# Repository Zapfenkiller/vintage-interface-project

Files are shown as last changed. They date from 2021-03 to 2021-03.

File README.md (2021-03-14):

## V. I. P. = **V**intage **I**nterface **P**roject

Ein altehrwürdiges fischertechnik Computing-Interface erhält Anschluss an den
I²C-Bus.

Die Eckdaten:

* I²C-Bus bis 400 kHz maximal
* I²C-Bus bis 100 kHz *ohne* Clock-Stretching
* Level-Shifter für den I²C-Bus eingebaut, Vcc = 1,8 V bis 5,0 V
* Bis zu 4 verschiedene V. I. P. im gleichen Bussegment adressierbar.
* Theoretisch beliebig viele Interfaces kaskadierbar
* I²C-Stecker entspricht 1:1 der I²C-Belegung des fischertechnik
[TX-Controllers 500995](https://ft-datenbank.de/details.php?ArticleVariantId=2f4d3bd4-b293-4f10-9b9d-c2faa8632409)

Was es über die alten Interfaces und den Adapter zu wissen gibt, ist bereits
als Mehrteiler in der ft:pedia veröffentlicht:

* Einführung und jede Menge Steckerbelegungen: [ft:pedia 2/2017, S. 63, V. I. P. - Teil 1](https://www.ftcommunity.de/ftpedia_ausgaben/ftpedia-2017-2.pdf)
* Stromversorgung und Motortreiber: [ft:pedia 3/2017, S. 57, V. I. P. - Teil 2](https://www.ftcommunity.de/ftpedia_ausgaben/ftpedia-2017-3.pdf)
* Eingänge und Watchdog: [ft:pedia 4/2017, S. 36, V. I. P. - Teil 3](https://www.ftcommunity.de/ftpedia_ausgaben/ftpedia-2017-4.pdf)

Hier im Repository sind alle Dokumente über die Hardware (Schaltplan und
Layout) und die Software (C-Sourcecode, Makefile, Hex-File und ein paar Files
für das AVR-Studio) zu finden.

Die Platine für den Adapter muss man sich selbst anfertigen.
Das Layout ist doppelseitig ausgeführt.
Eine Durchkontaktierung wird empfohlen.

Das Hex-File wird via AVR-Studio und STK500 in den angeschlossenen µC
programmiert.
Alternative Möglichkeiten sind natürlich ebenso verwendbar.
Dank des ISP-Steckers auf der Platine kann der µC direkt im Fertiggerät
geflasht werden.
Dieser ISP-Stecker ist 1:1 wie der 6-polige ISP-Stecker vom STK500 belegt.

An sich ist das Projekt abgeschlossen, evaluiert und die Software passt genau
zur Hardware.
Wer trotzdem selbst Hand anlegen möchte, kann dies gerne tun.
Die verwendete Toolchain (ist heutzutage auch alt, aber damit ist das Projekt
nun einmal entwickelt worden):

* µC-Referenz:   ATtiny2313 datasheet Rev. 2543I–AVR–04/06 (www.atmel.com)
* Compiler:      WinAVR-20100110 (http://www.sourceforge.net)
* Debugger:      AVR-Studio 4.18 (www.atmel.com)
* ISP:           Atmel STK500 (z. B. https://www.reichelt.de/Programmer-Entwicklungstools/AVR-STK-500/3/index.html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)
* PCB-CAD:       EAGLE 4.15 (http://www.cadsoft.de)

Gerade im ISP Bereich der Programmer gibt es erheblich günstigere Produkte
als das angegebene STK500.
Bitte im Bedarfsfall mal selbst beim Lieblingsbauteileshop mit dem Suchbegriff
"AVR programmer" stöbern.

Beim EAGLE kann möglicherweise auch eine modernere Version verwendet werden.
Ich habe das *nicht* ausprobiert.

Beim Compiler ändern sich von Version zu Version gerne mal die Definitionen
der Interruptbehandlung. 
Mit der angegebenen Version - und dem hiesigen makefile - klappt das auf
Anhieb.
Für andere Versionen ist möglicherweise massive Nacharbeit im C-Code zu
leisten.
Das Hex-File entspricht dem vorgestellten Sourcecode und kann sofort verwendet
werden.

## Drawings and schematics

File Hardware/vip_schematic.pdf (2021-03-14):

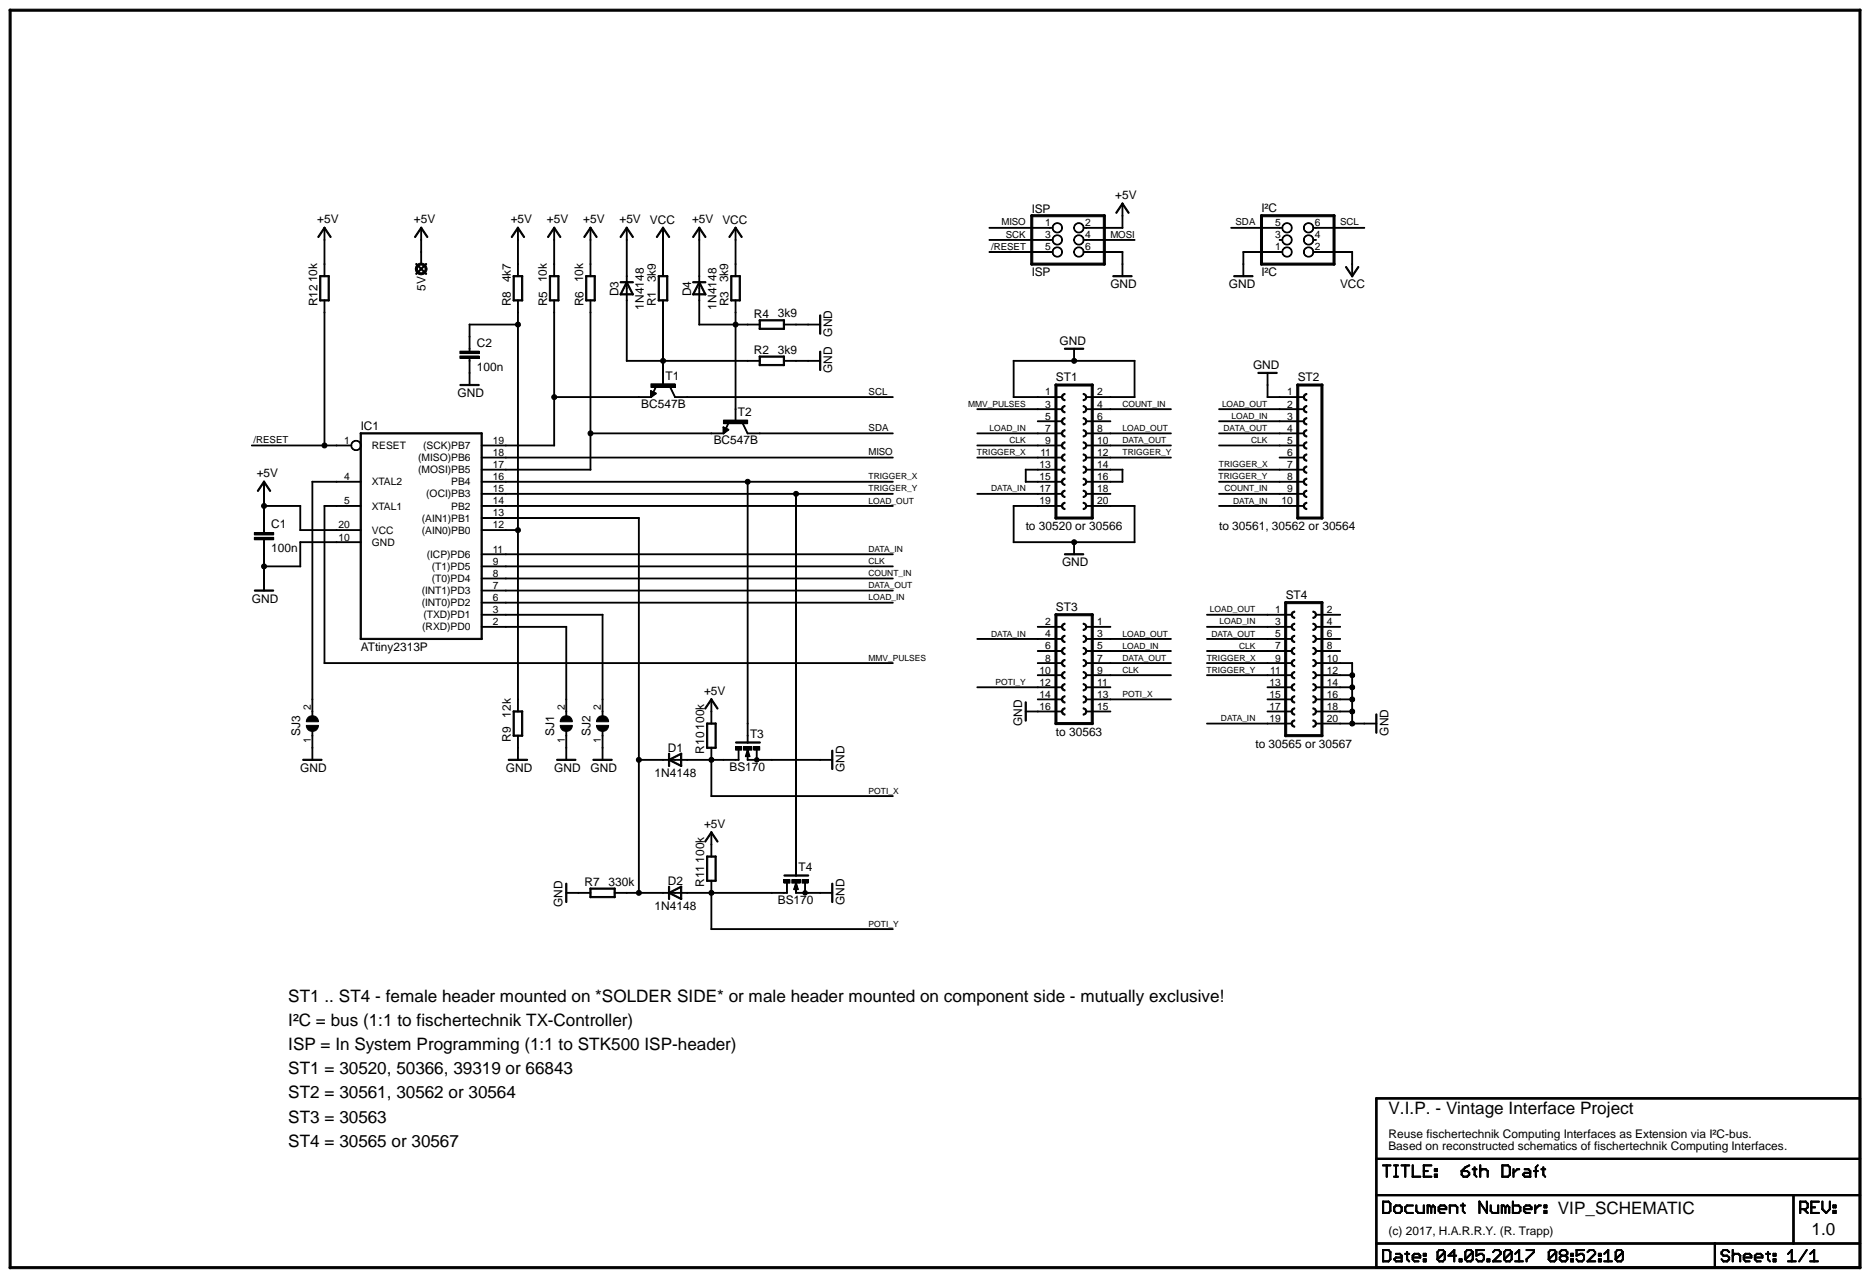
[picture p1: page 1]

ST1 .. ST4 - female header mounted on *SOLDER SIDE* or male header mounted on component side - mutually exclusive!
I²C = bus (1:1 to fischertechnik TX-Controller)
ISP = In System Programming (1:1 to STK500 ISP-header)

Reuse fischertechnik Computing Interfaces as Extension via I²C-bus.
Based on reconstructed schematics of fischertechnik Computing Interfaces.

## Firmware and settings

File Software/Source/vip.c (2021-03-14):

/*****************************************************************************\
 * File:         vip.c
 * Project:      Vintage Interface Project - V.I.P.
 * Initial date: May / 7 / 2017
 * Release rev.: 2017jun28
 * Copyright:    (c) 2017 R. Trapp / H.A.R.R.Y.
 *               All rights reserved.
 * Contact:      h_a_r_r_y_@users.sourceforge.net
 *               <https://forum.ftcommunity.de> => send PN to H.A.R.R.Y.
 * Description:  Adapt vintage fischertechnik Computing Interfaces to I²C-bus.
 *               The Interface thus can be addressed and operated as a slave.
 *               See documentation in archive or ft:pedia 2/2017 ff.
 *               Adjusts automatically to all known interface types:
 *               30520, 30561, 30562, 30563, 30564, 30565, 30566, 30567, 39319,
 *               66843
 *               ATtiny2313 runs off 8MHz, bus speed maximum 100kHz w/o clock-
 *               stretching. 400kHz relies on clock-stretching to slow down the
 *               bus-master!
 * Toolchain:    WinAVR-20100110 (http://www.sourceforge.net)
 *               ATtiny2313 datasheet revision = Rev. 2543I–AVR–04/06
 * WARNING:      This code contains inline assembly and plays lots of other
 *               tricks to optimize for topmost speed where necessary. Due to
 *               this everything must be done here in *one* file. If you dislike
 *               such a coding style you better stay away and stop reading now.
 *               There is the pure 'teaching book' "how-things-work" C-code in
 *               the neighbourhood. Read this equivalent to get an idea of the
 *               functionality. That code also compiles, links and works but if
 *               you compile and use that code, you will get a penalty of
 *               increased execution time - leading also to clock-stretching at
 *               100kHz bus.
 * License:      Redistribution and use in source and binary forms, with or
 *               without modification, are permitted provided that the following
 *               conditions are met:
 *               * Redistributions of source code must retain the above
 *                 copyright notice, this list of conditions and the following
 *                 disclaimer.
 *               * Redistributions in binary form must reproduce the above
 *                 copyright notice, this list of conditions and the following
 *                 disclaimer in the documentation and/or other materials
 *                 provided with the distribution.
 *               * Neither the name of the copyright holders nor the names of
 *                 contributors may be used to endorse or promote products
 *                 derived from this software without specific prior written
 *                 permission.
 * Disclaimer:   THIS SOFTWARE IS PROVIDED BY THE COPYRIGHT HOLDERS AND
 *               CONTRIBUTORS "AS IS" AND ANY EXPRESS OR IMPLIED WARRANTIES,
 *               INCLUDING, BUT NOT LIMITED TO, THE IMPLIED WARRANTIES OF
 *               MERCHANTABILITY AND FITNESS FOR A PARTICULAR PURPOSE ARE
 *               DISCLAIMED. IN NO EVENT SHALL THE COPYRIGHT OWNER OR
 *               CONTRIBUTORS BE LIABLE FOR ANY DIRECT, INDIRECT, INCIDENTAL,
 *               SPECIAL, EXEMPLARY, OR CONSEQUENTIAL DAMAGES (INCLUDING, BUT
 *               NOT LIMITED TO, PROCUREMENT OF SUBSTITUTE GOODS OR SERVICES;
 *               LOSS OF USE, DATA, OR PROFITS; OR BUSINESS INTERRUPTION)
 *               HOWEVER CAUSED AND ON ANY THEORY OF LIABILITY, WHETHER IN
 *               CONTRACT, STRICT LIABILITY, OR TORT (INCLUDING NEGLIGENCE OR
 *               OTHERWISE) ARISING IN ANY WAY OUT OF THE USE OF THIS SOFTWARE,
 *               EVEN IF ADVISED OF THE POSSIBILITY OF SUCH DAMAGE.
\*****************************************************************************/


// ============================================================================
//                         Set MCU clock to 8MHz!
//                      Everything here relies on it!
// ============================================================================

#ifndef F_CPU
#define F_CPU                 8000000UL
#else
#if (F_CPU!=8000000)
#error: F_CPU not set to 8MHz! Readjust project properties!
#endif
#endif


// ============================================================================
//                   Check for ATtiny2313 to be selected
// ============================================================================

#ifndef __AVR_ATtiny2313__
#error: This code is exclusively dedicated to ATtiny2313!
#endif
// Very close relatives could eventually also be used without changes.


/******************************************************************************\
 ******************************************************************************
 *
 *                                Prologue
 *
 ******************************************************************************
\******************************************************************************/


// ============================================================================
// Necessary includes
// ============================================================================

#include <avr/io.h>
#include <avr/interrupt.h>
#include <util/delay.h>


// ============================================================================
//                      Highly Recommended settings
// ============================================================================

// CKSEL3..0      = 0100   = internal 8MHz
// CKDIV          = 1      = no prescaling
// SUT1..0        = 10     = 65ms (slow rising power)
// BODLEVEL2..0   = 101    = 2.7V
// According to documentation just list here those fuse bits which need to get
// programmed ('0'). Unprogrammed ('1') fuses shall not be listed.
   FUSES = 
   {
      .low = (FUSE_SUT0 & FUSE_CKSEL3 & FUSE_CKSEL1 & FUSE_CKSEL0),
      .high = (FUSE_SPIEN & FUSE_BODLEVEL1),
      .extended = (FUSE_SELFPRGEN),
   };


// 'Security'     = Leave open since this code is released to the public.
   LOCKBITS = (LB_MODE_1);


// ============================================================================
// Assign signal names to ports
// ============================================================================

// ft Computing Interface:
// -----------------------
#define CLK                   PD5
#define COUNT_IN              PD4
#define DATA_IN               PD6
#define DATA_OUT              PD3
#define LOAD_IN               PD2
#define LOAD_OUT              PB2
#define MMV_PULSES            PA0
#define TRIGGER_X             PB4
#define TRIGGER_Y             PB3

// I²C bus:
// --------
#define TWIport               PORTB
#define TWIread               PINB
#define TWIddr                DDRB
#define TWIsclBit             PB7
#define TWIsdaBit             PB5

// Miscellaneous:
// --------------
#define MISO_ISP              PB6
#define SJ3                   PA1
#define SJ2                   PD1
#define SJ1                   PD0


// ============================================================================
// Reserve a few(!) registers - to speed up interrupt handling!
// ============================================================================
// Note: Need to do it here so that *everything* is aware of this reservation
//       at compile time!

/// \brief
/// Private storage register for the actual bus state.
// Use of r16 to r31 is mandatory due to CPI instructions
volatile register uint8_t  I2C_private_state asm ("r16");


/// \brief
/// Private storage register for the last received address+R/W field.
volatile register uint8_t  I2C_address_received asm ("r17");


// ============================================================================
// Unexpected Interrupts
// ============================================================================


/// \brief
/// Catches all unexpected interrupts.
/// \detail
/// What to do if any unexpected interrupt occurs? One could reset the appli-
/// cation immediately. And then? Unreliable functionality and really hard to
/// find root cause(s). Whom to report about the fault? No debug interface, no
/// user interface, ... so just ignore this unexpected interrupt. The ones we
/// are interested in are already handled.
EMPTY_INTERRUPT (BADISR_vect);
//  Up to here we assume 10 clocks (7 according to datasheet plus uncertainty)
//  So when RETI has passed we lost roughly 14 clocks @ 8MHz = 1750ns


/******************************************************************************\
 ******************************************************************************
 *
 *                       ft Computing Interface handling
 *                       ===============================
 *
 ******************************************************************************
\******************************************************************************/


// ============================================================================
// Some macros for easier coding
// ============================================================================
// Note: Do not rely on the compiler - force optimum code where necessary!

#define FT_IF_DEFAULT_DDRA    (0<<MMV_PULSES)
#define FT_IF_DEFAULT_PORTA   (1<<MMV_PULSES)
#define FT_IF_DEFAULT_DDRB    ((1<<TRIGGER_X) | (1<<TRIGGER_Y) | (1<<LOAD_OUT))
#define FT_IF_DEFAULT_PORTB   ((1<<TRIGGER_X) | (1<<TRIGGER_Y) | (0<<LOAD_OUT))
#define FT_IF_DEFAULT_DDRD    ((0<<DATA_IN) | (1<<CLK) | (0<<COUNT_IN) | (1<<DATA_OUT) | (1<<LOAD_IN))
#define FT_IF_DEFAULT_PORTD   ((1<<DATA_IN) | (1<<CLK) | (1<<COUNT_IN) | (0<<DATA_OUT) | (0<<LOAD_IN))

#define CLK_rise              asm volatile ("SBI %[port], %[bit]"::[port] "I" (_SFR_IO_ADDR(PORTD)), [bit] "I" (CLK))
#define CLK_fall              asm volatile ("CBI %[port], %[bit]"::[port] "I" (_SFR_IO_ADDR(PORTD)), [bit] "I" (CLK))
#define COMPARATOR_state      ACSR & (1<<ACO)
#define COUNT_IN_state        PIND & (1 << COUNT_IN)
#define COUNT_IN_count        TCNT0
#define DATA_IN_state         PIND & (1 << DATA_IN)
#define DATA_OUT_hi           asm volatile ("SBI %[port], %[bit]"::[port] "I" (_SFR_IO_ADDR(PORTD)), [bit] "I" (DATA_OUT))
#define DATA_OUT_lo           asm volatile ("CBI %[port], %[bit]"::[port] "I" (_SFR_IO_ADDR(PORTD)), [bit] "I" (DATA_OUT))
#define LOAD_IN_rise          asm volatile ("SBI %[port], %[bit]"::[port] "I" (_SFR_IO_ADDR(PORTD)), [bit] "I" (LOAD_IN))
#define LOAD_IN_fall          asm volatile ("CBI %[port], %[bit]"::[port] "I" (_SFR_IO_ADDR(PORTD)), [bit] "I" (LOAD_IN))
#define LOAD_OUT_rise         asm volatile ("SBI %[port], %[bit]"::[port] "I" (_SFR_IO_ADDR(PORTB)), [bit] "I" (LOAD_OUT))
#define LOAD_OUT_fall         asm volatile ("CBI %[port], %[bit]"::[port] "I" (_SFR_IO_ADDR(PORTB)), [bit] "I" (LOAD_OUT))
#define MMV_PULSES_state      PINA & (1 << MMV_PULSES)
#define TRIGGER_MMV(mmv)      PORTB &= (mmv); /*trigger_select;*/
#define TRIGGERs_release      PORTB |= ((1 << TRIGGER_X) | (1 << TRIGGER_Y))

#define DATA_IN_native        0b00000000
#define DATA_IN_inverted      0b11111111
#define no_motor_protection   0b11111111
#define protect_motors        0b00111111
#define MMV_worst_5k_ms       5
#define MMV_worst_100k_ms     75
#define MMV_trigger_width_us  5
#define ID_sampling_after_us  50

#define DELAY_1_MCU_CLOCK     asm volatile ("NOP"::)


// ============================================================================
// Enumerations for better code readability
// ============================================================================

enum
{  // Interface identification
   FT_IF_UNKNOWN   = 0,
   FT_IF_30520     = 9,
   FT_IF_30561     = 1,
   FT_IF_30562     = 2,
   FT_IF_30563     = 3,
   FT_IF_30564     = 4,
   FT_IF_30565     = 5,
   FT_IF_30566     = 6,
   FT_IF_30567     = 7,
// FT_IF_30568     = 8, RESERVATION!
   FT_IF_39319     = 6,
   FT_IF_66843     = 9
};


enum
{  // Channel selection for analog readback
   FT_IF_EX = (~(1<<TRIGGER_X)),
   FT_IF_EY = (~(1<<TRIGGER_Y))
};



// ============================================================================
// Variable definitions
// ============================================================================

uint8_t  ft_identifier = FT_IF_UNKNOWN;
uint8_t  ft_data_inversion_mask = DATA_IN_native;
uint8_t  ft_motor_protection = protect_motors;


// ============================================================================
// Resistance read back (analog inputs EX / EY)
// ============================================================================
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
int main (void)
{


// ============================================================================
// Enumerations for better code readability
// ============================================================================

   enum
   {  // Commands to register 1
      VIP_READ_EX_cmd = 0x80,
      VIP_READ_EY_cmd = 0x40,
      VIP_READ_ID_cmd = 0xFF
   };


// ============================================================================
// Variable definitions
// ============================================================================

   uint8_t  answer = 0;
   uint8_t  received = 0;
   uint8_t  command = 0;
   uint8_t  flag = 0;


// ============================================================================
// Initializations
// ============================================================================

   // Init IO ports
   PORTD = I2C_DEFAULT_PORTD | FT_IF_DEFAULT_PORTD;
   DDRD  = I2C_DEFAULT_DDRD | FT_IF_DEFAULT_DDRD;
   PORTB = (1<<MISO_ISP) | FT_IF_DEFAULT_PORTB;
   DDRB  = (0<<MISO_ISP) | FT_IF_DEFAULT_DDRB;
   PORTA = (1<<SJ3) | FT_IF_DEFAULT_PORTA;
   DDRA  = (0<<SJ3) | FT_IF_DEFAULT_DDRA;

   // Identify ft-interface by its response
   FT_IF_init_and_identify();

   // Start bus interface
   I2C_Set_Early_Reply_Reg_0 (0xFF);
   I2C_Set_Early_Reply_Reg_1 (answer);
   I2C_Setup();


// ============================================================================
// Application main loop
// ============================================================================

   // And this is all that needs to be done from now on
   while (1)
   {
      switch(I2C_GetAddress())
      {
         case  I2C_RD_REG_0:
               FT_IF_sample_from_switches();
               while (I2C_GetState() == I2C_ACCESSING)
               {
                  I2C_PutData(FT_IF_shift_from_switches());
               }
               break;
         case  I2C_RD_REG_1:
               while (I2C_GetState() == I2C_ACCESSING)
               {
                  I2C_PutData(answer);
               }
               break;
         case  I2C_WR_REG_0:
               flag = 0;
               while (1)
               {
                  received = I2C_GetData();
                  if (I2C_GetState() == I2C_ACCESSING)
                  {
                     FT_IF_shift_to_motors(received);
                     flag = 1;
                  }
                  else
                     break;
               }
               if (flag != 0)
                  FT_IF_latch_to_motors();
               break;
         case  I2C_WR_REG_1:
               flag = 0;
               while (1)
               {
                  received = I2C_GetData();
                  if (I2C_GetState() == I2C_ACCESSING)
                  {
                     command = received;
                     flag = 1;
                  }
                  else
                     break;
               }
               if (flag != 0)
                  switch (command)
                  {
                     case  VIP_READ_ID_cmd:
                           answer = FT_IF_get_identifier();
                           I2C_Set_Early_Reply_Reg_1 (answer);
                           break;
                     case  VIP_READ_EX_cmd:
                           I2C_Retire();
                           answer = FT_IF_get_resi(FT_IF_EX);
                           I2C_Set_Early_Reply_Reg_1 (answer);
                           I2C_Setup();
                           break;
                     case  VIP_READ_EY_cmd:
                           I2C_Retire();
                           answer = FT_IF_get_resi(FT_IF_EY);
                           I2C_Set_Early_Reply_Reg_1 (answer);
                           I2C_Setup();
                           break;
                     default:
                           answer = 0;
                           I2C_Set_Early_Reply_Reg_1 (answer);
                  }
               break;
         default:
               ;  // <= ask the compiler about why!!!
      }  // switch(...)
   }  // while (1)
}  // main()


/*****************************************************************************\
 *
 * "$Id:$"
 *
 * "$Log:$"
 *
\*****************************************************************************/
